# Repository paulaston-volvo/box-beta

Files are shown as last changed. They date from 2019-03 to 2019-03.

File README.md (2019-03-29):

# Box Monitor Beta

##

### Construction
A general top-tip is make sure your workspace is clear that you have all the tools and parts you need. 
Tools you will need: 
- Small flat-head screw driver (2.4mm)
- Wire cutters
- Needle nose pliers
- Hot glue gun
- Soldering iron
- Solder
- Black nasty/electrical tape
- Multimeter

#### Step 1
Start by fitting the resistors to the board. Cut the legs short to ensure a tight fit into the board. You may want to use the pliers to help push the pins into the breadboard. 
The resistors should match the colours on the diagram. If they don't, here is a handy guide: https://learn.sparkfun.com/tutorials/resistors/decoding-resistor-markings

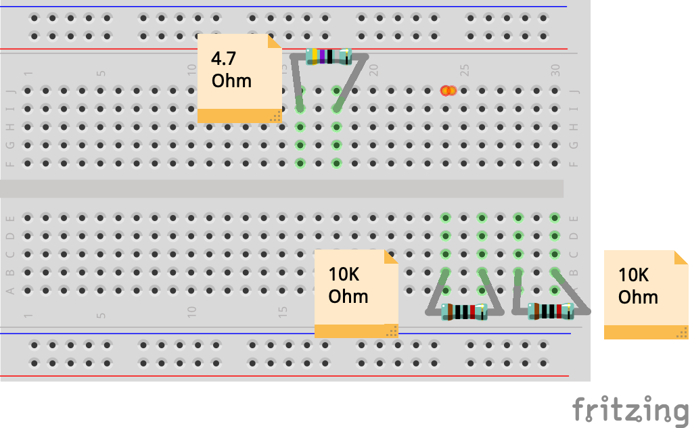
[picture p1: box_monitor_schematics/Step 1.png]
Step 1


#### Step 2
Start wiring. Try to cut the wires so they fit as snugly to the board as possible. _Use the single core wire_ for this.
Holes H1-H16 down to B2-B6 will be covered by the Fona board and unusable, wires can be run tightly under the board to the left of that.

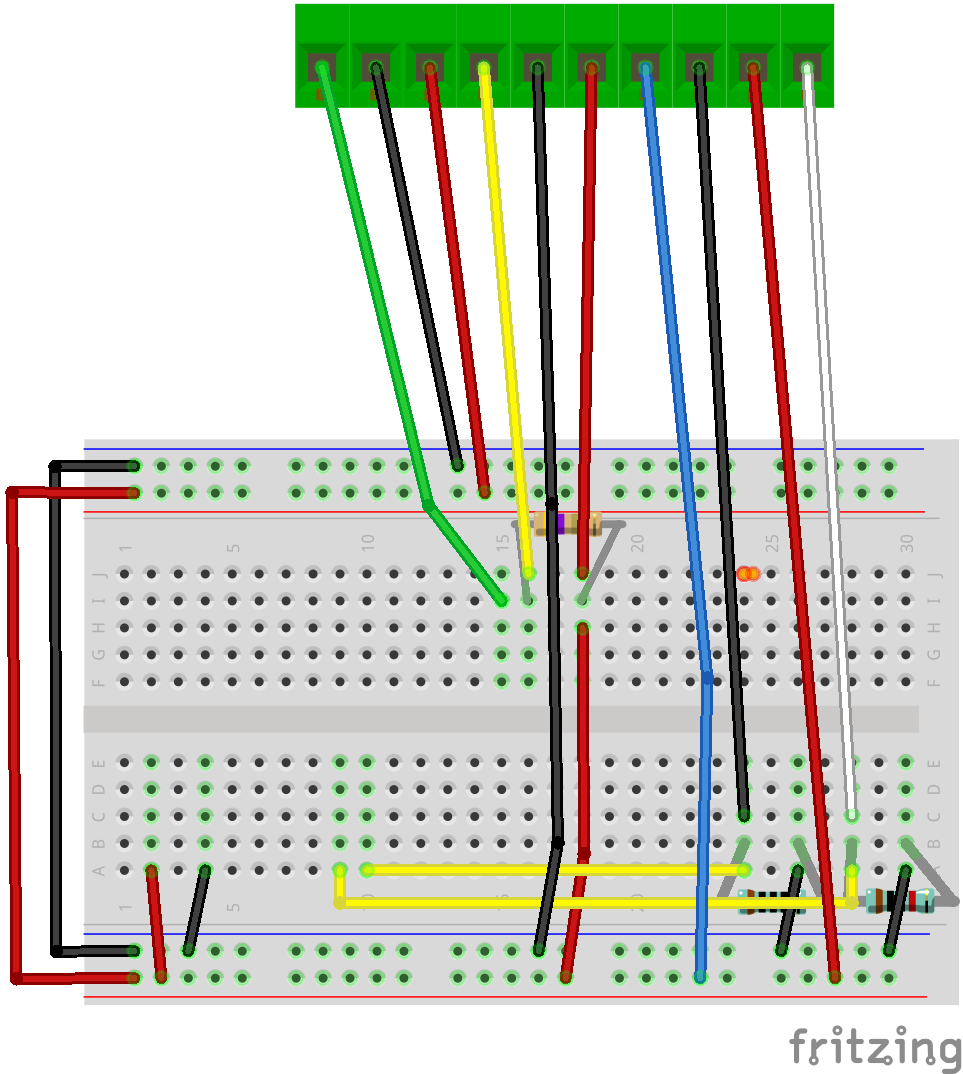
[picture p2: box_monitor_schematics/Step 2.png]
Step 2


#### Step 3
Place the Fona board into the breadboard (_Note: The pins will have to be soldered to the Fona board before insertion_)
You can skip this step and do it later if you wish.
Also remember to add the SIM card before placing the Fona board.

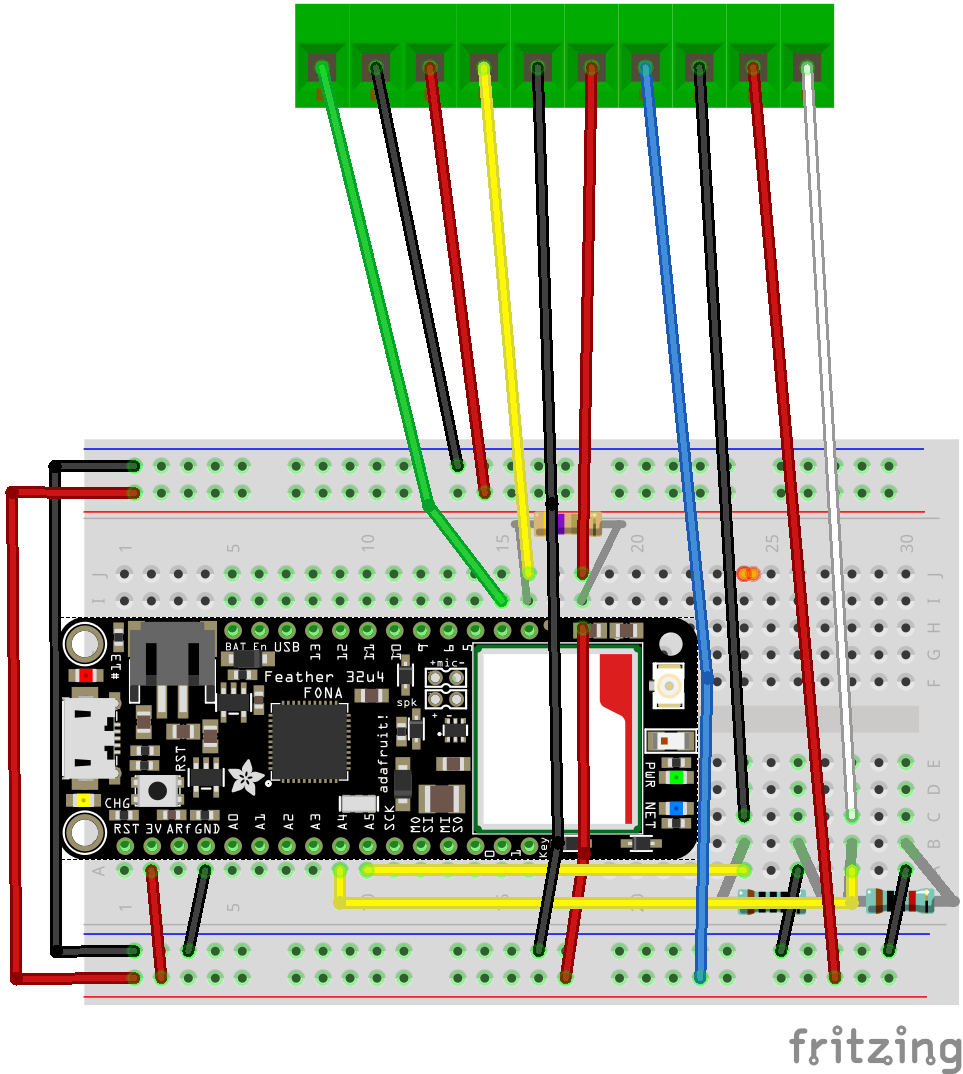
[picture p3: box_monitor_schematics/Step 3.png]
Step 3


#### Step 4
Add the connectors from the status light LEDs

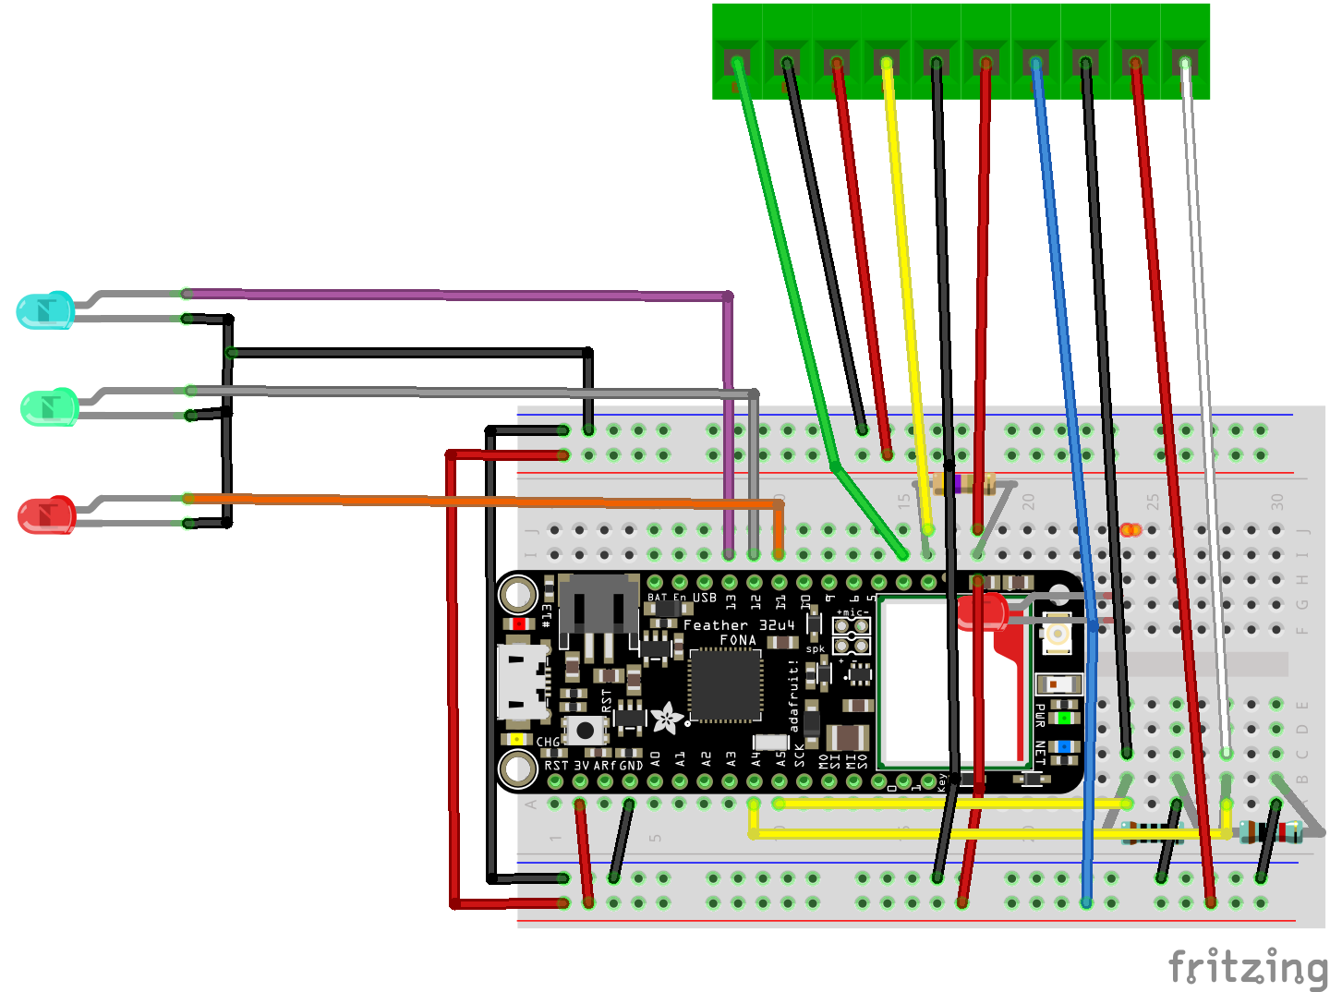
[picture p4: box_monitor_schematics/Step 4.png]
Step 4


#### Step 5
Wire in the sensor cables from the box, making sure to match the colours! Also remember to run them through the hole in the box first!

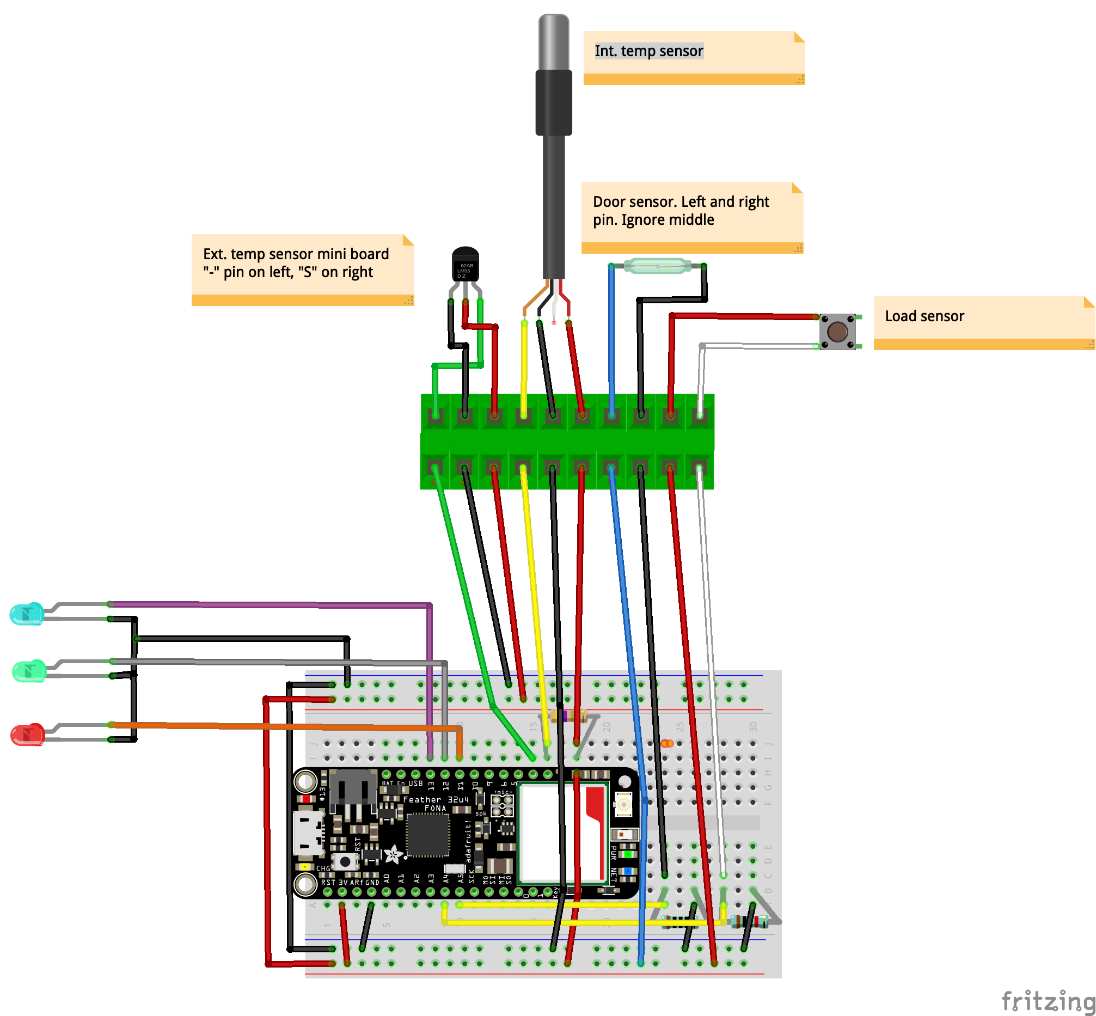
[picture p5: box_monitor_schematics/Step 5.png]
Step 5


#### Step 6 
Plug in the batteries and the GSM antenna and youre done!

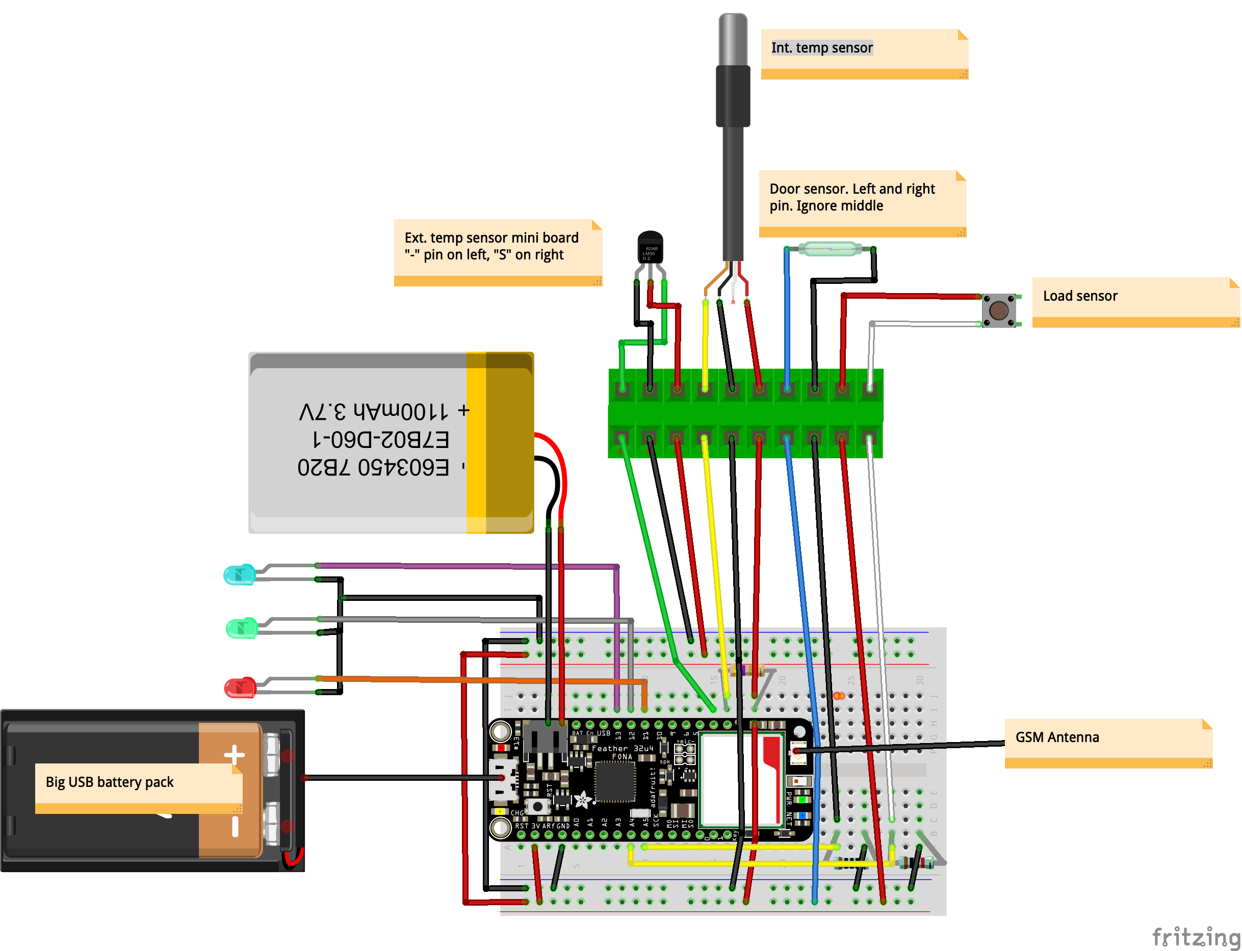
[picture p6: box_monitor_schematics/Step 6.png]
Step 6


#### Notes:

 - The small battery may not have a full charge which will affect the ability to send data, but when the board is plugged into your laptop to load the programme, it should give it enough boost.
 -  The big battery will only have a 75% charge when you buy it. Top it up from a phone charger plugged into the wall (not a laptop, it takes ages.)
 
 # Software installation

##

### Arduino IDE
First install the Arduino IDE on your machine: http://www.arduino.cc/en/Main/Software

After you have downloaded and installed the latest version of Arduino IDE, you will need to start the IDE and navigate to the Preferences menu.

Prefs

We will be adding a URL to the new Additional Boards Manager URLs option. The list of URLs is comma separated, and you will only have to add each URL once. New Adafruit boards and updates to existing boards will automatically be picked up by the Board Manager each time it is opened. The URLs point to index files that the Board Manager uses to build the list of available & installed boards.

To find the most up to date list of URLs you can add, you can visit the list of third party board URLs on the Arduino IDE wiki. We will only need to add one URL to the IDE in this example, but you can add multiple URLS by separating them with commas. Copy and paste the link below into the Additional Boards Manager URLs option in the Arduino IDE preferences.

https://adafruit.github.io/arduino-board-index/package_adafruit_index.json

### Libraries

There all also a number of Libraries you'll need to install that run the sensors, JSON package and other things. These are all in https://github.com/paulaston-volvo/box-beta/tree/master/Libraries

A guide to installation is here: https://www.arduino.cc/en/guide/libraries

After you've installed everything, _close and restart the IDE_.

### Using with Arduino IDE 
Since the Feather 32u4 uses an ATmega32u4 chip running at 8 MHz, you can pretty easily get it working with the Arduino IDE. 

Now that you have added the appropriate URLs to the Arduino IDE preferences, you can open the Boards Manager by navigating to the Tools->Board menu.

Board

Once the Board Manager opens, click on the category drop down menu on the top left hand side of the window and select Contributed. You will then be able to select and install the boards supplied by the URLs added to the prefrences. In the example below, we are installing support for Adafruit AVR Boards, but the same applies to all boards installed with the Board Manager.

Next, quit and reopen the Arduino IDE to ensure that all of the boards are properly installed. You should now be able to select and upload to the new boards listed in the Tools->Board menu.

Board

### Blink
Run a test program.

Plug in the Feather 32u4 and wait for it to be recognized by the OS (just takes a few seconds). It will create a serial/COM port, you can now select it from the dropdown, it'll even be 'indicated' as Feather 32u4!

Board

Go to File > New and then copy in the code below. 

```
// the setup function runs once when you press reset or power the board
void setup() {
  // initialize digital pin 13 as an output.
  pinMode(13, OUTPUT);
}

// the loop function runs over and over again forever
void loop() {
  digitalWrite(13, HIGH);   // turn the LED on (HIGH is the voltage level)
  delay(1000);              // wait for a second
  digitalWrite(13, LOW);    // turn the LED off by making the voltage LOW
  delay(1000);              // wait for a second
}
```

Click to Tick icon in the top left to validate the code, when that comes back okay, click the Arrow icon to send it to the board. You'll see the blink rate on the inbuilt LED in board change. Great success!

## Installing the Box Box software

Download and open the "box_monitor_beta.ino" in the Arduino IDE: https://github.com/paulaston-volvo/box-beta/blob/master/box_monitor_beta/box_monitor_beta.ino

Navigate down to
```
//Box ID
char id[13] = "locker881801"
```

And change the locker ID to match the box 

- locker169872
- locker439243
- locker734714
- locker948515

Go to Tools > Serial Monitor and select. Make sure you set it to Baudrate 115200 & Both NL & CR

monitor

Click the arrow icon to send it to the board. 

The software will flash to the board and it will run through the setup process. 
 - connect to the GSM network
 - Enable GPRS (data connection)
    - Both of these may take a while  
 - Get first set of data from sensors
 - Process as JSON
 - Send to server
 - Get response
 - And then
    - If error, try again
    - If succesfull, set green light and wait for box to open or close
    
You can see this on the serial monitor: 

```
Failed to turn on GPRS. Trying again...
	---> AT+CIPSHUT
	<--- SHUT OK
	---> AT+CGATT=1
	<--- ERROR
	---> AT+CIPSHUT
	<--- SHUT OK
	---> AT+CGATT=1
	<--- ERROR
	---> AT+CIPSHUT
	<--- SHUT OK
	---> AT+SAPBR=0,1
	<--- ERROR
```
It will do this quite a few times. It's normal and nothing to worry about

```
Failed to turn on GPRS. Trying again...
---> AT+CIPSHUT
	<--- SHUT OK
	---> AT+CGATT=1
	<--- ERROR
	---> AT+CIPSHUT
	<--- SHUT OK
	---> AT+CGATT=1
	<--- OK
	---> AT+SAPBR=3,1,"CONTYPE","GPRS"
	<--- OK
	---> AT+SAPBR=3,1,"APN","TM"
	<--- OK
	---> AT+CSTT="TM","",""
	<--- OK
	---> AT+SAPBR=3,1,"USER",""
	<--- OK
	---> AT+SAPBR=3,1,"PWD",""
	<--- OK
	---> AT+SAPBR=1,1
	<--- OK
	---> AT+CIICR
	<--- OK
BOX IS CLOSED
	---> AT+CIPSHUT
	<--- SHUT OK
	---> AT+CGATT=1
	<--- OK
	---> AT+SAPBR=3,1,"CONTYPE","GPRS"
	<--- OK
	---> AT+SAPBR=3,1,"APN","TM"
	<--- OK
	---> AT+CSTT="TM","",""
	<--- OK
	---> AT+SAPBR=3,1,"USER",""
	<--- OK
	---> AT+SAPBR=3,1,"PWD",""
	<--- OK
	---> AT+SAPBR=1,1
	<--- ERROR
```
Succesfully booted and connected

```
{
  "thingId": "locker2",
  "batteryStatus": 6.593555,
  "intemp": 85,
  "outtemp": 85,
  "lidOpen": false,
  "loaded": false
}
```
This is the data that it sends. You can see here if the sensors are working properly. (Note: intemp & outtemp 85, means "sensors okay. No reading taken yet. This is okay)
- thingId: Locker ID
- batteryStatus: battery voltage
- intemp: temperature in the box
- outtemp: temperature outside the box
- lidopen: false = closed, true = open
- loaded: false = nothing in there, true = loaded

```
	---> AT+HTTPTERM
	<--- ERROR
	---> AT+HTTPINIT
	<--- OK
	---> AT+HTTPPARA="CID"
	<--- OK
	---> AT+HTTPPARA="UA"
	<--- OK
	---> AT+HTTPPARA="URL"
	<--- OK
	---> AT+HTTPPARA="CONTENT"
	<--- OK
	---> AT+HTTPDATA=102,10000
	<--- DOWNLOAD
	<--- OK
	---> AT+HTTPACTION=1
	<--- OK
Status: 200
```
Data succesfully sent. If it can't send, it will try again until it does. 

## Operating sequence

When the box boots, it goes through the sequence above until it can successfully send a status update to the server. If it fails to send 5 times it will reboot itself and try to reconnect. If it is stuck in the bootup sequence, press the reset button on the Adafruit board. 

reset

It's the tiny push button at the bottom left above the 3V pin. 

Once the box is set it listens for the lid to open or close. On Open it will collect the sensor data, parse it as JSON and send it to the server. When the lid closes it will do the same, if the box is loaded it will send that information. 

It will also send an update to the server every 9 minutes. 

Again, if it fails to connect at any point in this more than 5 times, it will reboot and try again. Sometimes it may take multiple reboots (a few minutes), but 95% of the time this will sort the problem. 

## The lights 

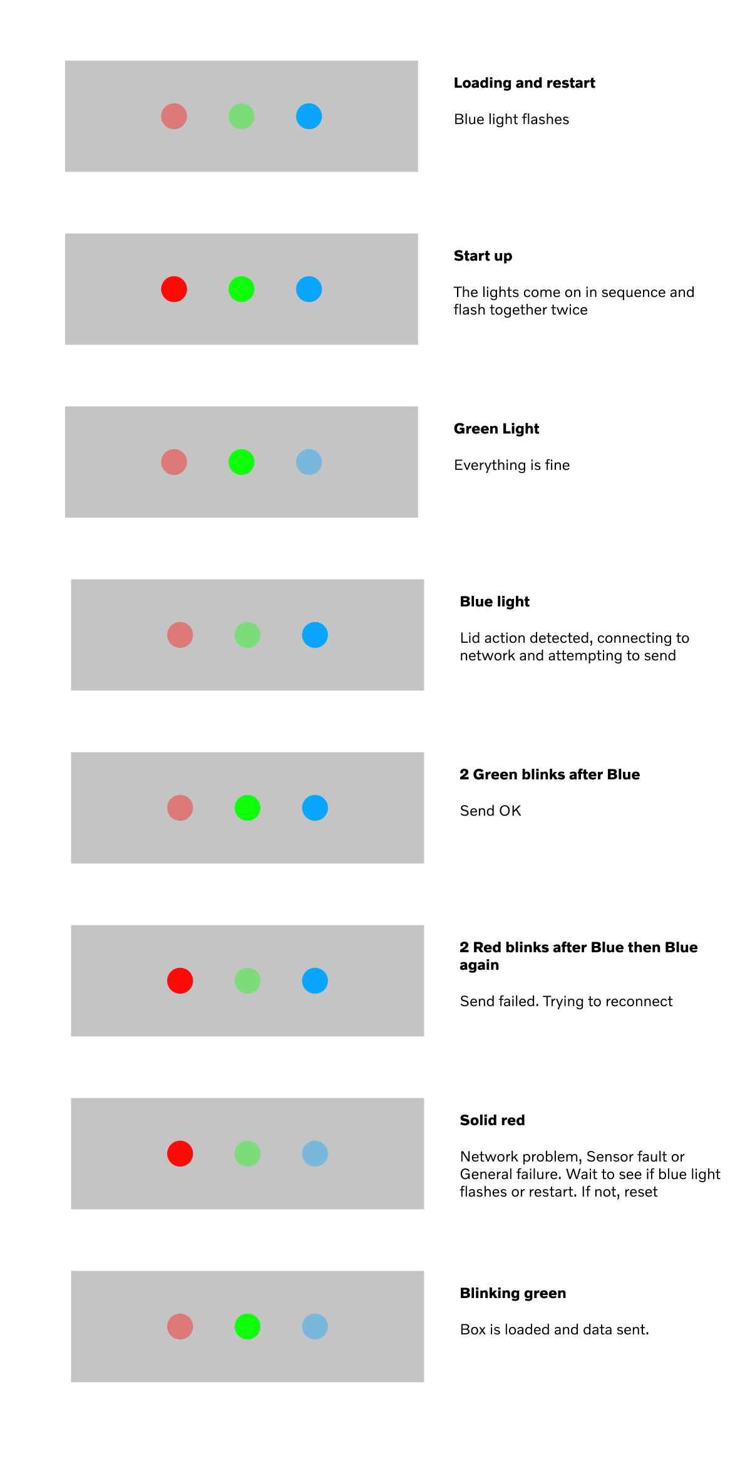
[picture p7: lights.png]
lights


## Troubleshooting

**In general**
- Try the reset button.
- Unlug both batteries for 20 seconds and reconnect.
- Do the above, then flash the Blink sketch above before re-flashingt the box software (like reformatting the thing)

**Green and Red light. Not blinking**
The small battery voltage is too low and it needs to be powered up via USB cable from laptop, or the powerbank

**The box doesn't seem to work after I unplug my laptop**
- Sometime unplugging the serial monitor can screw things up. Hit the reset button

**The box seems to keep cycling and never sends**
- Check that the GSM antenna is firmly attached
- It could be that the small battery is depleted - it needs this for the power spike when sending _even with the big battery plugged in_. See below.

**There is a permanent red light**
 - The small battery could be depleted. 
 - Try a restart.
 - If that doesn't fix it, plug the board into your latop for 5 mins to boost the small battery (it seems to be faster and better than the power bank) and reflash the software. 
 
 **The sensors are giving bad readings or not working**
 - Check all the connections into the box. Wires can break in the terminal block if screwed too tightly and subject to a lot of movement or pulling.
 - Check connections from terminal block to breadboard. Something may have worked loose. 
 
 **The lid opening or closing isn't detected**
 - Check the position of the magnet and the reed switch. They need to be nice and snug together when the lid is shut.
 
 **It doesn't seem to be connecting to the cloud**
 - Check the antenna is securely fitted. 
 - Check if something has changed in the backend.
 - Check the credit in the SIM
 - Flash the simtest sketch to the board (https://github.com/paulaston-volvo/box-beta/blob/master/simtest/simtest.ino) and check that you are able to connect to the network, and that you can activate GPRS
 	- If you can, then the problem most likely lies with the backend somewhere
	- If you can't then the problem is with:
		- The SIM
		- The hardware (if this is the case, try a new Adafruit Fona board)

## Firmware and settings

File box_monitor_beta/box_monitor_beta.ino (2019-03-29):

// Include the libraries we need
    #include <OneWire.h>
    #include <DallasTemperature.h>
    #include <ArduinoJson.h>
    #include "Adafruit_FONA.h"
    #include <MemoryFree.h>

// Data wire is plugged into port 2 on the Arduino
    #define ONE_WIRE_BUS_1 2
    #define ONE_WIRE_BUS_2 3
    #define VBATPIN A9

//Setup FONA
    #define FONA_RX  9
    #define FONA_TX  8
    #define FONA_RST 4
    #define FONA_RI  7
    
    // this is a large buffer for replies
    char replybuffer[255];
    
    // We default to using software serial. If you want to use hardware serial
    // (because softserial isnt supported) comment out the following three lines 
    // and uncomment the HardwareSerial line
    #include <SoftwareSerial.h>
    SoftwareSerial fonaSS = SoftwareSerial(FONA_TX, FONA_RX);
    SoftwareSerial *fonaSerial = &fonaSS;
    
    // Hardware serial is also possible!
    //  HardwareSerial *fonaSerial = &Serial1;
    
    // Use this for FONA 800 and 808s
    Adafruit_FONA fona = Adafruit_FONA(FONA_RST);
    // Use this one for FONA 3G
    //Adafruit_FONA_3G fona = Adafruit_FONA_3G(FONA_RST);
    
    uint8_t readline(char *buff, uint8_t maxbuff, uint16_t timeout = 0);
    uint8_t type;
       
// Setup a oneWire instance to communicate with any OneWire devices (not just Maxim/Dallas temperature ICs)
    OneWire oneWire_in(ONE_WIRE_BUS_1);
    OneWire oneWire_out(ONE_WIRE_BUS_2);

// Pass our oneWire reference to Dallas Temperature. 
    DallasTemperature sensor_inbox(&oneWire_in);
    DallasTemperature sensor_outbox(&oneWire_out);

//Box ID - Remember to change this depending on the box
//char id[13] = "locker881801";
//char id[13] = "locker169872";
//char id[13] = "locker439243";
char id[13] = "locker734714";
//char id[13] = "locker948515";

//Set up reed switch 
int switchReed=A5;

//Debug
int pinState = 0;

//Pressure sensor
int pressSensor=A4;

//States
float boxTemp;
float outTemp;
bool doorStatus;
bool  boxLoaded;
float batteryLevel;

//Intervals - movied into function due to issue with long integers
//int intervalTimer=1800000;

//Events
boolean boxClosedEventExecuted = false;
boolean boxOpenEventExecuted = false;
boolean sendFail = false;

//Debug
int passFlag = 0;

//Lamps
int gprsPin = 13;   
int failPin = 12;  
int okayPin = 11; 



void setup(void){

  pinMode(switchReed, INPUT);
  pinMode(gprsPin, OUTPUT); 
  pinMode(failPin, OUTPUT); 
  pinMode(okayPin, OUTPUT); 
  pinMode(pressSensor, INPUT);
   
  // Start up the library
  sensor_inbox.begin();
  sensor_outbox.begin();

  //Initialise - Fancy lights
  digitalWrite(gprsPin, HIGH);
  delay(1000);
  digitalWrite(okayPin, HIGH);
  delay(1000);
  digitalWrite(failPin, HIGH);
  delay(1000);
  digitalWrite(gprsPin, LOW);
  digitalWrite(okayPin, LOW);
  digitalWrite(failPin, LOW);
  delay(500);
  digitalWrite(gprsPin, HIGH);
  digitalWrite(okayPin, HIGH);
  digitalWrite(failPin, HIGH);
  delay(500);
  digitalWrite(gprsPin, LOW);
  digitalWrite(okayPin, LOW);
  digitalWrite(failPin, LOW);
  
  //FONA
  //while (!Serial);

  Serial.begin(115200);
  Serial.println(F("Initializing....(May take 3 seconds)"));
  digitalWrite(okayPin, HIGH);
  fonaSerial->begin(4800);
  if (! fona.begin(*fonaSerial)) {
    Serial.println(F("Couldn't find FONA"));
    while (1);
  }

  
  // Print module IMEI number.
  char imei[16] = {0}; // MUST use a 16 character buffer for IMEI!
  uint8_t imeiLen = fona.getIMEI(imei);
  if (imeiLen > 0) {
    Serial.print("Module IMEI: "); Serial.println(imei);
  }

  // Optionally configure a GPRS APN, username, and password.
  // You might need to do this to access your network's GPRS/data
  // network.  Contact your provider for the exact APN, username,
  // and password values.  Username and password are optional and
  // can be removed, but APN is required.
  fona.setGPRSNetworkSettings(F("TM"), F(""), F(""));

  // Optionally configure HTTP gets to follow redirects over SSL.
  // Default is not to follow SSL redirects, however if you uncomment
  // the following line then redirects over SSL will be followed.
  //fona.setHTTPSRedirect(true);
  //*****************************
  

}

/*
 * Main function, get and show the temperature
 */
void loop(void)
{ 

  //DEBUG
  /*Serial.println("+++DEBUG+++");
  Serial.println(pressSensor);
  pinState = digitalRead(pressSensor);
  //pinState = analogRead(pressSensor);
  Serial.println(pinState);*/
    
    //This routine checks the voltage on the battery (if it exists) and returns that value.  Should be in the 3.2-4.2 range depending upon the battery used
    float measuredvbat = analogRead(VBATPIN);
    measuredvbat *= 2;    // we divided by 2, so multiply back
    measuredvbat *= 3.3;  // Multiply by 3.3V, our reference voltage
    measuredvbat /= 1024; // convert to voltage
     // Serial.print("VBat: " ); Serial.println(measuredvbat);
     batteryLevel = (measuredvbat);

    //Get and get the box temperature
    sensor_inbox.requestTemperatures();
    sensor_outbox.requestTemperatures();
    float tempCin = sensor_inbox.getTempCByIndex(0);
    float tempCout = sensor_outbox.getTempCByIndex(0);
    
      boxTemp = (tempCin);
      outTemp = (tempCout);
      //Serial.println(boxTemp);
      //Serial.println(outTemp);

    //Detect failed send
    if (sendFail == true){
      //Serial.println(F("sendFail = true"));
      enableGPRS();
    }

    //Detect Door Status
    //Closed
    if (digitalRead(switchReed)==1){
      doorStatus=false;
      if (boxClosedEventExecuted == false){
        boxClosedEvent();
      };
    }
    //Open
    else{
      doorStatus=true;
      if (boxOpenEventExecuted == false){
        boxOpenEvent();
      };
    };

    //Detect if box loaded
    //Loaded
    if (digitalRead(pressSensor)==1){
      boxLoaded=true;
      //digitalWrite(okayPin, HIGH);
    }
    //Not loaded
    else{
      boxLoaded=false;
      //digitalWrite(okayPin, LOW);
    } 

    //Send update at interval
    intervalUpdate();

}

//When box is opened
void boxOpenEvent(){ 
  Serial.println(F("BOX IS OPEN"));
  enableGPRS();
  boxOpenEventExecuted = true;
  boxClosedEventExecuted = false;    
  digitalWrite(failPin, HIGH);


 if(!fona.enableGPRS(true)) {
  enableGPRS();
 }
 else{
  sendCurrentStatus();
 }
}

//When box is closed
void boxClosedEvent(){ 
  Serial.println(F("BOX IS CLOSED"));
  //enableGPRS();
  boxClosedEventExecuted = true;   
  boxOpenEventExecuted = false; 

  if(!fona.enableGPRS(true)) {
  enableGPRS();
 }
 else{
  sendCurrentStatus();
 }
}

//Send update at timed intervals
void intervalUpdate(){ 
  static unsigned long lastTime = 0;
  const long interval = 1800000;
  unsigned long now = millis();
  //Debugging stuff
  /*Serial.println(interval);
  Serial.print("now: ");
  Serial.println(now);*/
  if ( now - lastTime > interval) {
      lastTime = now;
        enableGPRS();
  }

}

void enableGPRS(){
    digitalWrite(failPin, LOW);
   
   while(!fona.enableGPRS(true)) {
    fona.enableGPRS(false);
      Serial.println(F("Failed to turn on GPRS. Trying again..."));
      digitalWrite(failPin, HIGH);
      digitalWrite(gprsPin, LOW);
      delay(200);
       
    if(fona.enableGPRS(true)) {
      Serial.println(F("GPRS is on.")); 
      digitalWrite(failPin, LOW);
      digitalWrite(gprsPin, HIGH);
      
      break;
    }
  }
  sendCurrentStatus();

}


//Send all current data
void sendCurrentStatus(){

  digitalWrite(gprsPin, HIGH);
  //Get network time and add 20** to year 
   /*if (!fona.enableNTPTimeSync(true, F("pool.ntp.org")))
   Serial.println(F("Failed to enable"));

  char timeStamp[23];
  String timeWithYear;
  fona.getTime(timeStamp, 23);  // make sure replybuffer is at least 23 bytes!
  //Serial.print(F("Time = ")); Serial.println(timeStamp);
  timeStamp[strlen(timeStamp) - 1] = 0;

  timeWithYear = "20";
  timeWithYear += &timeStamp[1];
  Serial.println(timeWithYear);*/

  
  //Output as JSON
  //DynamicJsonBuffer  jsonBuffer(200);
  StaticJsonBuffer<200> jsonBuffer;
  JsonObject& root = jsonBuffer.createObject();

  root["thingId"] = id;
  //root["timestamp"] = timeWithYear;
  root["batteryStatus"] = batteryLevel;
  root["intemp"] = boxTemp;
  root["outtemp"] = outTemp;
  root["lidOpen"] = doorStatus;
  root["loaded"] = boxLoaded;

  root.prettyPrintTo(Serial);
  Serial.println("");
  Serial.print(F("freeMemory()="));
  Serial.println(freeMemory());

  char jsonChar[156];
  root.printTo((char*)jsonChar, root.measureLength() + 1);

  //See the string output of root string output 
  //Serial.print(F("jsonChar: "));
  //Serial.println(jsonChar);
  
  
  // Post data to website
  uint16_t statuscode;
  int16_t length;
  char url[49]="http://labsvoc.azurewebsites.net/api/VolvoLocker";
  //char url[49]="failtosendtovolvoapi.com";
  Serial.flush();
  Serial.println(F("****"));
  //Failed to send
  if (!fona.HTTP_POST_start(url, F("application/json"), (uint8_t *) jsonChar, strlen(jsonChar), &statuscode, (uint16_t *)&length)) {
    //jsonBuffer.clear();
    Serial.println(F("Failed!"));
    //Serial.print("Length: ");
    //Serial.println(length);
    signalStrength();
    Serial.print(F("freeMemory()="));
    Serial.println(freeMemory());
    sendFail = true;
    digitalWrite(failPin, HIGH);
    delay(500);
    digitalWrite(failPin, LOW);
    delay(200);
    digitalWrite(failPin, HIGH);
    delay(500);
    digitalWrite(failPin, LOW);

  }
  else{
  
  while (length > 0) {
    while (fona.available()) {
    char c = fona.read();

  #if defined(__AVR_ATmega328P__) || defined(__AVR_ATmega168__)
              //Wait until data register empty. 
              loop_until_bit_is_set(UCSR0A, UDRE0);
              
              UDR0 = c;
  #else
              Serial.write(c);
  #endif

      length--;
      if (! length) break;
    }
  }
  Serial.println(F("\n****"));
  fona.HTTP_POST_end();
  sendFail = false;
  //Serial.print("Length: ");
  //Serial.println(length);
  Serial.print(F("freeMemory()="));
  Serial.println(freeMemory());
  digitalWrite(failPin, LOW);
  digitalWrite(okayPin, HIGH);
  delay(500);
  digitalWrite(okayPin, LOW);
  delay(200);
  digitalWrite(okayPin, HIGH);
  delay(500);
  digitalWrite(okayPin, LOW);
  delay(500);
  digitalWrite(okayPin, HIGH);
  digitalWrite(gprsPin, LOW);
  signalStrength();
  }
}

void signalStrength() {
        // read the RSSI
        uint8_t n = fona.getRSSI();
        int8_t r;

        Serial.print(F("Signal Strength = ")); Serial.print(n); Serial.print(": ");
        if (n == 0) r = -115;
        if (n == 1) r = -111;
        if (n == 31) r = -52;
        if ((n >= 2) && (n <= 30)) {
          r = map(n, 2, 30, -110, -54);
        }
        Serial.print(r); Serial.println(F(" dBm"));
}





//Error reporting
//01 = Internal temp sensor
void errorReporting(int error){
  Serial.print("There's a fuck up somewhere: ");
  Serial.print(error);
}

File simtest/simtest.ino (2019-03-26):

/***************************************************
  This is an example for our Adafruit FONA Cellular Module

  Designed specifically to work with the Adafruit FONA
  ----> http://www.adafruit.com/products/1946
  ----> http://www.adafruit.com/products/1963
  ----> http://www.adafruit.com/products/2468
  ----> http://www.adafruit.com/products/2542

  These cellular modules use TTL Serial to communicate, 2 pins are
  required to interface
  Adafruit invests time and resources providing this open source code,
  please support Adafruit and open-source hardware by purchasing
  products from Adafruit!

  Written by Limor Fried/Ladyada for Adafruit Industries.
  BSD license, all text above must be included in any redistribution
 ****************************************************/

/*
THIS CODE IS STILL IN PROGRESS!

Open up the serial console on the Arduino at 115200 baud to interact with FONA

Note that if you need to set a GPRS APN, username, and password scroll down to
the commented section below at the end of the setup() function.
*/
#include "Adafruit_FONA.h"
#include <ArduinoJson.h>

#define FONA_RX  9
#define FONA_TX  8
#define FONA_RST 4
#define FONA_RI  7

// this is a large buffer for replies
char replybuffer[255];

// We default to using software serial. If you want to use hardware serial
// (because softserial isnt supported) comment out the following three lines 
// and uncomment the HardwareSerial line
#include <SoftwareSerial.h>
SoftwareSerial fonaSS = SoftwareSerial(FONA_TX, FONA_RX);
SoftwareSerial *fonaSerial = &fonaSS;

// Hardware serial is also possible!
//  HardwareSerial *fonaSerial = &Serial1;

// Use this for FONA 800 and 808s
Adafruit_FONA fona = Adafruit_FONA(FONA_RST);
// Use this one for FONA 3G
//Adafruit_FONA_3G fona = Adafruit_FONA_3G(FONA_RST);

uint8_t readline(char *buff, uint8_t maxbuff, uint16_t timeout = 0);

uint8_t type;

void setup() {
  while (!Serial);

  Serial.begin(115200);
  Serial.println(F("Initializing....(May take 3 seconds)"));

  fonaSerial->begin(4800);
  if (! fona.begin(*fonaSerial)) {
    Serial.println(F("Couldn't find FONA"));
    while (1);
  }

  
  // Print module IMEI number.
  char imei[16] = {0}; // MUST use a 16 character buffer for IMEI!
  uint8_t imeiLen = fona.getIMEI(imei);
  if (imeiLen > 0) {
    Serial.print("Module IMEI: "); Serial.println(imei);
  }

  // Optionally configure a GPRS APN, username, and password.
  // You might need to do this to access your network's GPRS/data
  // network.  Contact your provider for the exact APN, username,
  // and password values.  Username and password are optional and
  // can be removed, but APN is required.
  fona.setGPRSNetworkSettings(F("TM"), F(""), F(""));

  // Optionally configure HTTP gets to follow redirects over SSL.
  // Default is not to follow SSL redirects, however if you uncomment
  // the following line then redirects over SSL will be followed.
  //fona.setHTTPSRedirect(true);

  printMenu();
}

void printMenu(void) {
  Serial.println(F("-------------------------------------"));
  Serial.println(F("[?] Print this menu"));
  Serial.println(F("[a] read the ADC 2.8V max (FONA800 & 808)"));
  Serial.println(F("[b] read the Battery V and % charged"));
  Serial.println(F("[C] read the SIM CCID"));
  Serial.println(F("[U] Unlock SIM with PIN code"));
  Serial.println(F("[i] read RSSI"));
  Serial.println(F("[n] get Network status"));
  Serial.println(F("[v] set audio Volume"));
  Serial.println(F("[V] get Volume"));
  Serial.println(F("[H] set Headphone audio (FONA800 & 808)"));
  Serial.println(F("[e] set External audio (FONA800 & 808)"));
  Serial.println(F("[T] play audio Tone"));
  Serial.println(F("[P] PWM/Buzzer out (FONA800 & 808)"));


  // SMS
  Serial.println(F("[N] Number of SMSs"));
  Serial.println(F("[r] Read SMS #"));
  Serial.println(F("[R] Read All SMS"));
  Serial.println(F("[d] Delete SMS #"));
  Serial.println(F("[s] Send SMS"));
  Serial.println(F("[u] Send USSD"));
  
  // Time
  Serial.println(F("[y] Enable network time sync (FONA 800 & 808)"));
  Serial.println(F("[Y] Enable NTP time sync (GPRS FONA 800 & 808)"));
  Serial.println(F("[t] Get network time"));

  // GPRS
  Serial.println(F("[G] Enable GPRS"));
  Serial.println(F("[g] Disable GPRS"));
  Serial.println(F("[l] Query GSMLOC (GPRS)"));
  Serial.println(F("[w] Read webpage (GPRS)"));
  Serial.println(F("[W] Post to website (GPRS)"));

  // GPS
  if ((type == FONA3G_A) || (type == FONA3G_E) || (type == FONA808_V1) || (type == FONA808_V2)) {
    Serial.println(F("[O] Turn GPS on (FONA 808 & 3G)"));
    Serial.println(F("[o] Turn GPS off (FONA 808 & 3G)"));
    Serial.println(F("[L] Query GPS location (FONA 808 & 3G)"));
    if (type == FONA808_V1) {
      Serial.println(F("[x] GPS fix status (FONA808 v1 only)"));
    }
    Serial.println(F("[E] Raw NMEA out (FONA808)"));
  }
  
  Serial.println(F("[S] create Serial passthru tunnel"));
  Serial.println(F("-------------------------------------"));
  Serial.println(F(""));

}
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

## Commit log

2019-03-25 updated schematics
    [Breadboard - Step 1.fzz, Breadboard layout.fzz, Step 2.fzz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]
2019-03-25 added gsm arial to schematic 6
    [Step 6.fzz]
2019-03-29 fixed interbval timing integer
    [box_monitor_beta.ino]
